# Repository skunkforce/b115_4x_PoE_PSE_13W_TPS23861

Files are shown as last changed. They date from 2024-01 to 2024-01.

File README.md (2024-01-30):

# edgy_board number b115
This design is part of the [edgy board project](https://github.com/skunkforce/edgy_boards). It provides the functionality of the PoE PSE [tps23861](https://www.ti.com/lit/ds/symlink/tps23861.pdf?HQS=dis-dk-null-digikeymode-dsf-pf-null-wwe&ts=1679496827255). [view it in browser with kiCanvas](https://kicanvas.org/?github=https://github.com/skunkforce/b115_4x_PoE_PSE_13W_TPS23861/tree/master/board)

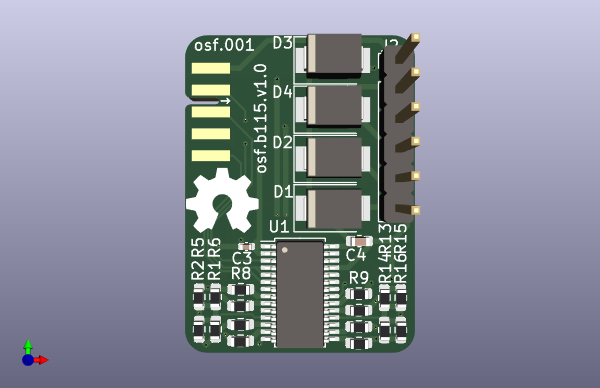
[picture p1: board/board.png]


# getting started
This repository uses submodules. After cloning use the command 

```$ git submodule update --init --recursive```

to pull the submodules before opening the project with kicad. 

# Tests
Tests can be found in [TESTS.md](TESTS.md)

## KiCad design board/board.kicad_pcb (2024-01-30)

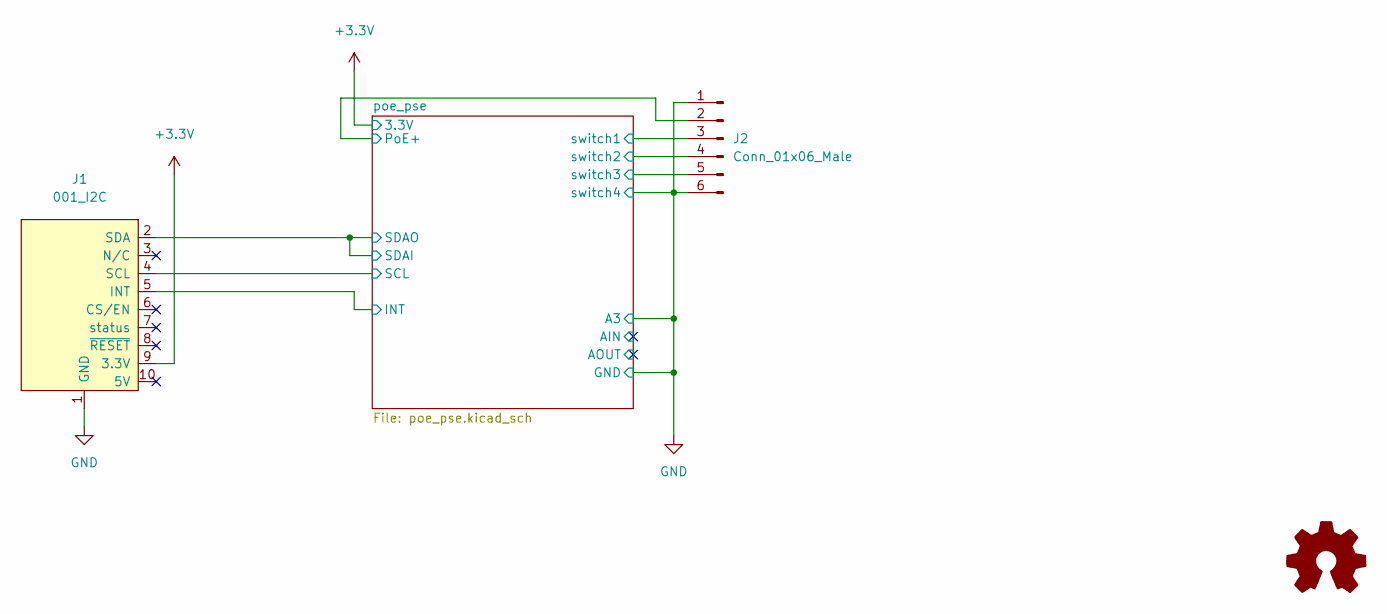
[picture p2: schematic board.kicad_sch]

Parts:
J1: 001_I2C; on_edge_2x05_device
J2: Conn_01x06_Male; PinHeader_1x06_P2.54mm_Vertical
LOGO1: Logo_Open_Hardware_Small; OSHW-Symbol_6.7x6mm_SilkScreen

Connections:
+3.3V: J1.9 (3.3V); also elsewhere on the board
/poe_pse/INT: J1.5 (INT); also elsewhere on the board
/poe_pse/PoE+: J2.2; also elsewhere on the board
/poe_pse/SCL: J1.4 (SCL); also elsewhere on the board
/poe_pse/SDAI: J1.2 (SDA); also elsewhere on the board
/poe_pse/switch1: J2.3; also elsewhere on the board
/poe_pse/switch2: J2.4; also elsewhere on the board
/poe_pse/switch3: J2.5; also elsewhere on the board
GND: J1.1 (GND), J2.1, J2.6; also elsewhere on the board

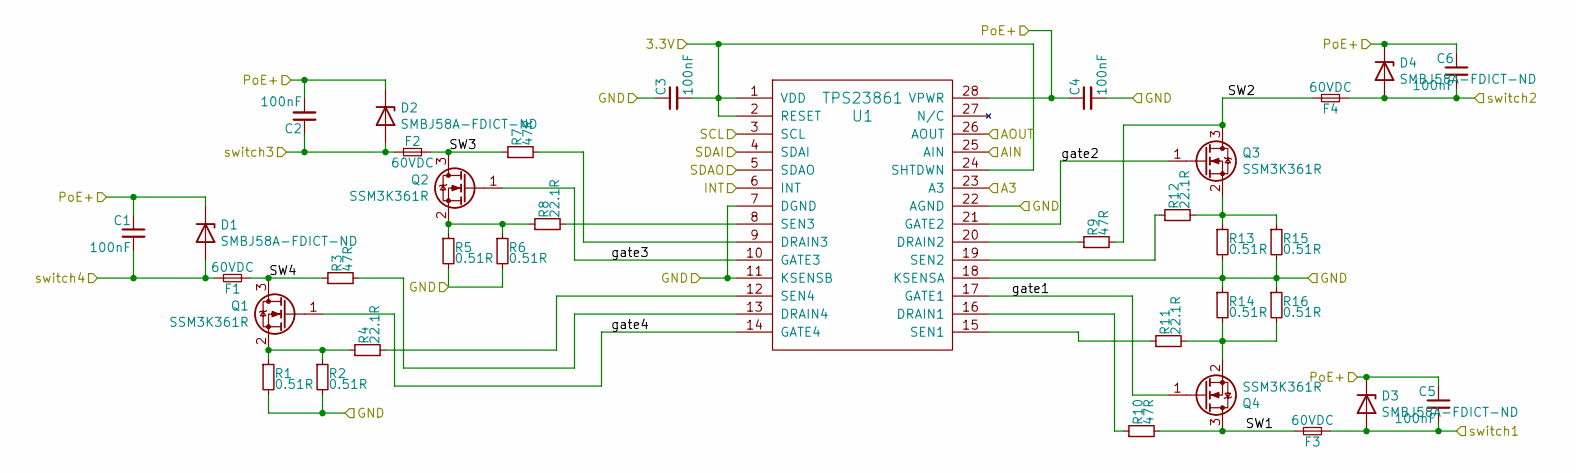
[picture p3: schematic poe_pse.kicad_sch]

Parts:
C1, C2, C4, C5, C6: 100nF; C_0603_1608Metric; Voltage 100V; Digi-Key_PN 1276-6807-1-ND
C3: 100nF; C_0603_1608Metric; Voltage 6.3V; Digi-Key_PN 1276-6807-1-ND
D1, D2, D3, D4: SMBJ58A-FDICT-ND; D_SMB; lcsc C157526
F1, F2, F3, F4: 60VDC; Fuse_1206_3216Metric; Digi-Key_PN F2569CT-ND
Q1, Q2, Q3, Q4: SSM3K361R; SOT-23; lcsc C5444678
R1, R2, R5, R6, R13, R14, R15, R16: 0.51R; R_0603_1608Metric; Tolerance 1%; Digi-Key_PN P.51AJCT-ND
R3, R7, R9, R10: 47R; R_0603_1608Metric; Tolerance 5%; Digi-Key_PN ‎RMCF0603JT47R0CT-ND‎
R4, R8, R11, R12: 22.1R; R_0603_1608Metric; Tolerance 1%; Digi-Key_PN P22.1HCT-ND
U1: TPS23861; TSSOP-28_4.4x9.7mm_P0.65mm; Digi-Key_PN 296-37969-5-ND

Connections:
+3.3V: C3.2, U1.1 (VDD), U1.2 (RESET), U1.24 (SHTDWN); also elsewhere on the board
/poe_pse/AIN: U1.25 (AIN)
/poe_pse/AOUT: U1.26 (AOUT)
/poe_pse/INT: U1.6 (INT); also elsewhere on the board
/poe_pse/PoE+: C1.1, C2.2, C4.1, C5.1, C6.1, D1.1 (A1), D2.1 (A1), D3.1 (A1), D4.1 (A1), U1.28 (VPWR); also elsewhere on the board
/poe_pse/SCL: U1.3 (SCL); also elsewhere on the board
/poe_pse/SDAI: U1.4 (SDAI), U1.5 (SDAO); also elsewhere on the board
/poe_pse/SW1: F3.2, Q4.3 (D), R10.2
/poe_pse/SW2: F4.2, Q3.3 (D), R9.2
/poe_pse/SW3: F2.1, Q2.3 (D), R7.1
/poe_pse/SW4: F1.1, Q1.3 (D), R3.1
/poe_pse/gate1: Q4.1 (G), U1.17 (GATE1)
/poe_pse/gate2: Q3.1 (G), U1.21 (GATE2)
/poe_pse/gate3: Q2.1 (G), U1.10 (GATE3)
/poe_pse/gate4: Q1.1 (G), U1.14 (GATE4)
/poe_pse/switch1: C5.2, D3.2 (A2), F3.1; also elsewhere on the board
/poe_pse/switch2: C6.2, D4.2 (A2), F4.1; also elsewhere on the board
/poe_pse/switch3: C2.1, D2.2 (A2), F2.2; also elsewhere on the board
GND: C1.2, C3.1, C4.2, D1.2 (A2), F1.2, R1.2, R2.2, R5.2, R6.2, R13.2, R14.1, R15.2, R16.1, U1.7 (DGND), U1.11 (KSENSB), U1.18 (KSENSA), U1.22 (AGND), U1.23 (A3); also elsewhere on the board
unnamed: Q1.2 (S), R1.1, R2.1, R4.1
unnamed: Q2.2 (S), R5.1, R6.1, R8.1
unnamed: Q3.2 (S), R12.2, R13.1, R15.1
unnamed: Q4.2 (S), R11.2, R14.2, R16.2
unnamed: R10.1, U1.16 (DRAIN1)
unnamed: R9.1, U1.20 (DRAIN2)
unnamed: R7.2, U1.9 (DRAIN3)
unnamed: R3.2, U1.13 (DRAIN4)
unnamed: R11.1, U1.15 (SEN1)
unnamed: R12.1, U1.19 (SEN2)
unnamed: R8.2, U1.8 (SEN3)
unnamed: R4.2, U1.12 (SEN4)

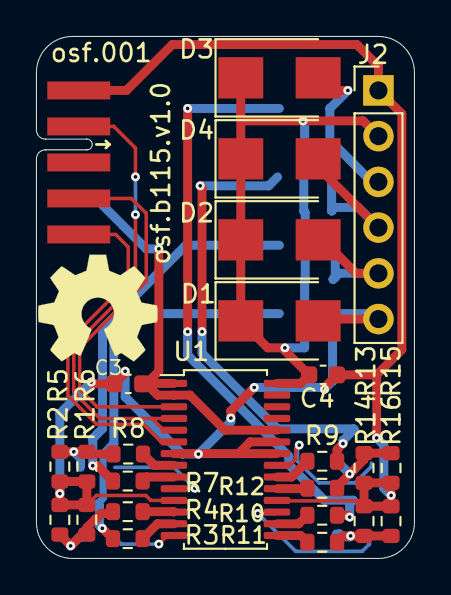
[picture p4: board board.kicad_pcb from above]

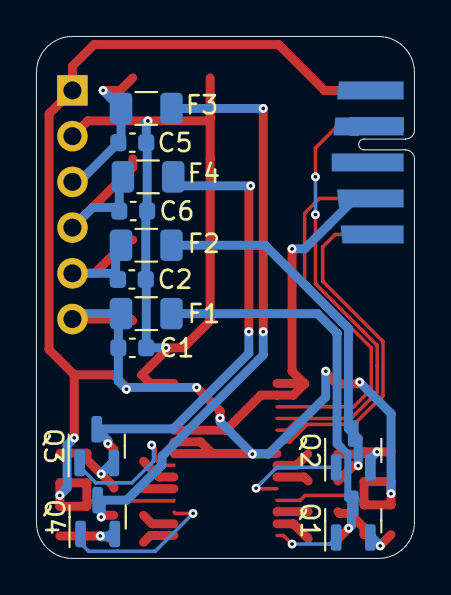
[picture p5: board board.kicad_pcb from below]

Board: 2 copper layers, 21.0 x 29.0 mm, 38 parts (12 on the bottom side), 29 nets.

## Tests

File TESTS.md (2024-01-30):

# minimal test
## setup
connected b051 and b103 to I2C for 3.3V power and 48V and the input to a b075 to the pin header. 
## results
b075 initialized and worked.

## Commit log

2023-03-27 placed and routed
    [board.kicad_pcb, board.kicad_sch, implementation.kicad_sch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]
2023-03-27 broke out address lines
    [board.kicad_pcb, board.kicad_sch, poe_pse.kicad_sch]
2023-12-15 moved symbol to local library
    [board.kicad_sch, poe_pse.kicad_sch]
2024-01-30 added lcsc part numbers
    [board.kicad_pcb, board.kicad_sch, poe_pse.kicad_sch]
2026-02-04 refactored to single sided board and added AIN pull up
2026-02-04 fixed incorrect fuse strength
